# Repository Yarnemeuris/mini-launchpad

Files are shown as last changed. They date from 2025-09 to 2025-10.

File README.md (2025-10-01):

# mini-launchpad

Mini launchpad is a midi devicde and control surface for Ableton. When connected to a computer it can: send midi notes, start and stop clips, be used as audio output, change the volume and change paramaters. When not connected to a computer it can: play notes and create sound with a synth.

## connected to Ableton

Mini launchpad is specificy designed to be used with Ableton Live. When you connect it to a computer, it uses an internal usb hub so you can use it as an audio output and send commands through Ableton. When connected it can be used as a midi keyboard or start and stop cilps in the session view.

## standalone

When mini launchpad is in standalone mode, you can only use the midi keyboard. This will send midi into a synthesizer, which will then play sound. The syth can be customized a bit via the encoders at the top, but you can customize it fully if you reprogram the pi.

## compontents

Mini Launchpad has an 8x8 grid of buttons, wired to 4 io expanders. There are also 8 encoders connected to another io expander. The io expanders are used so that the microcontroller doesn't have to poll for changes, but that it can use interupts instead. This way every button press will be registerd and you can press every button at the same time. There are also some extra controll buttons and lights that are wired directly to the microcontroller. But these will also use interupt.

For audio there is a PCM5100 I²S DAC. This will convert the digital audio to a line output. Then there is an amplifier that amplifies the sound. You can also just use the line out.

## playing notes

Actually playing notes is a big part of the luanchpad. There are 2 ways to do this.
- Option 1 is that the notes are layed out linearly. This means that in the bottom left corner is a C, moving right goes up a note and moving up goes up an octave. You can change the octave of the rows by moving up and down. This is also the default option when the launchpad boots up. It looks like this:

layout 1

- Option 2 is for the notes to be layed out in a c scale. The bottom left note is still a C and going right still goes up a note. But going up goes up a fourth instead of an octave. This layout is the default layout on the Ableton Push and lloks like this:

layout 2

## progress

The current progress.

- [x] Design the schematic.
- [x] Design the pcb.
- [x] Design the case.
- [x] Write the firmware.

I know not a lot of the features I talk about aren't implemented yet. But for SoM those won't be included. This is beacuse mini midi magic started pretty late and it doesn't really have an end date yet. So by the end of mini midi magic this will all be implemented. The current features that aren't implemented are:
- Connecting to Ableton Live.
- Playing and controlling things in Ableton Live.
- Having a more complex and better synthesizer.
- Being able to change the synthesizer.
- Using the launchpad as an audio interface.
- And I might even add more features.

  I am also unsure if any of the code works and if the case is fully correct. Because I don't have the physical board myself. This will also change before the end of mini midi magic.

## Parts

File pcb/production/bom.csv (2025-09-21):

Designator | Footprint | Quantity | Value | LCSC Part #
C1, C17, C18, C2, C21, C22 | 0805 | 6 | 10µF | C15850
C10, C11, C12, C13, C14, C4, C5, C7, C8, C9 | 0805 | 10 | 100nF | C476766
C15, C16 | 0805 | 2 | 22pF | C1804
C19 | 1206 | 1 | 250µF
C20, C23 | 0805 | 2 | 50nF | C107154
C24 | 1206 | 1 | 250µF | C412252
C3, C6 | 0805 | 2 | 1µF | C28323
D1, D2, D3 | LED_D3.0mm | 3 | LED | C3028820
J1 | PinHeader_1x08_P2.54mm_Vertical | 1 | Conn_01x08_Socket
J2 | PinHeader_1x06_P2.54mm_Vertical | 1 | Conn_01x06_Socket | C5383115
J4 | Jack_3.5mm_CUI_SJ1-3524N_Horizontal | 1 | AudioJack3_Ground | C4992816
J5 | USB_C_Receptacle_G-Switch_GT-USB-7010ASV | 1 | USB_C_Receptacle_USB2.0_16P | C2988369
Q1 | SOT-23 | 1 | AO3401A | C15127
R1, R16 | 0402 | 2 | 5.1K | C105872
R10, R13 | 0402 | 2 | 10 | C138066
R11, R12, R4 | 0402 | 3 | 10K
R14, R15 | 0402 | 2 | 100 | C106232
R2, R3 | 0402 | 2 | 27 | C138021
R5, R7 | 0402 | 2 | 1K | C11702
R6, R8, R9 | 0402 | 3 | 220 | C112291
RV2 | Potentiometer_Alpha_RD902F-40-00D_Dual_Vertical | 1 | R_Potentiometer_Dual | C470285
SW1, SW10, SW11, SW12, SW13, SW14, SW15, SW16, SW17, SW18, SW19, SW2, SW20, SW21, SW22, SW23, SW24, SW25, SW26, SW27, SW28, SW29, SW3, SW30, SW31, SW32, SW33, SW34, SW35, SW36, SW37, SW38, SW39, SW4, SW40, SW41, SW42, SW43, SW44, SW45, SW46, SW47, SW48, SW49, SW5, SW50, SW51, SW52, SW53, SW54, SW55, SW56, SW57, SW58, SW59, SW6, SW60, SW61, SW62, SW63, SW64, SW7, SW8, SW9 | SW_Cherry_MX_1.00u_PCB | 64 | ~
SW65 | SW_E-Switch_EG2219_DPDT_Angled | 1 | SW_DPDT_x2 | C2848873
SW66, SW67, SW68, SW69, SW70, SW71, SW72, SW73 | RotaryEncoder_Alps_EC11E-Switch_Vertical_H20mm_MountingHoles | 8 | RotaryEncoder_Switch_MP | C202365
SW75, SW76, SW77, SW78, SW79, SW80, SW81, SW83 | SW_Cherry_MX_1.00u_PCB | 8 | SW_Push
U1, U11, U2, U3, U4 | QFN-28-1EP_6x6mm_P0.65mm_EP4.25x4.25mm | 5 | MCP23017_ML | C639770
U10 | SOIC-8_5.3x5.3mm_P1.27mm | 1 | W25Q128JVS | C97521
U14, U15 | SOIC-8_3.9x4.9mm_P1.27mm | 2 | LM386 | C23573
U5 | QFN-32-1EP_5x5mm_P0.5mm_EP3.3x3.3mm | 1 | CP2615-xx-xM | C1521596
U6 | TSSOP-16_4.4x5mm_P0.65mm | 1 | TMUX1574PW | C2673443
U7 | QSOP-16_3.9x4.9mm_P0.635mm | 1 | CH334R | C4154405
U8 | QFN-56-1EP_7x7mm_P0.4mm_EP3.2x3.2mm | 1 | RP2040 | C2040
U9 | TO-252-2 | 1 | NCP1117-3.3_TO252 | C154606
Y1 | Crystal_SMD_3225-4Pin_3.2x2.5mm | 1 | 12MHz | C9002

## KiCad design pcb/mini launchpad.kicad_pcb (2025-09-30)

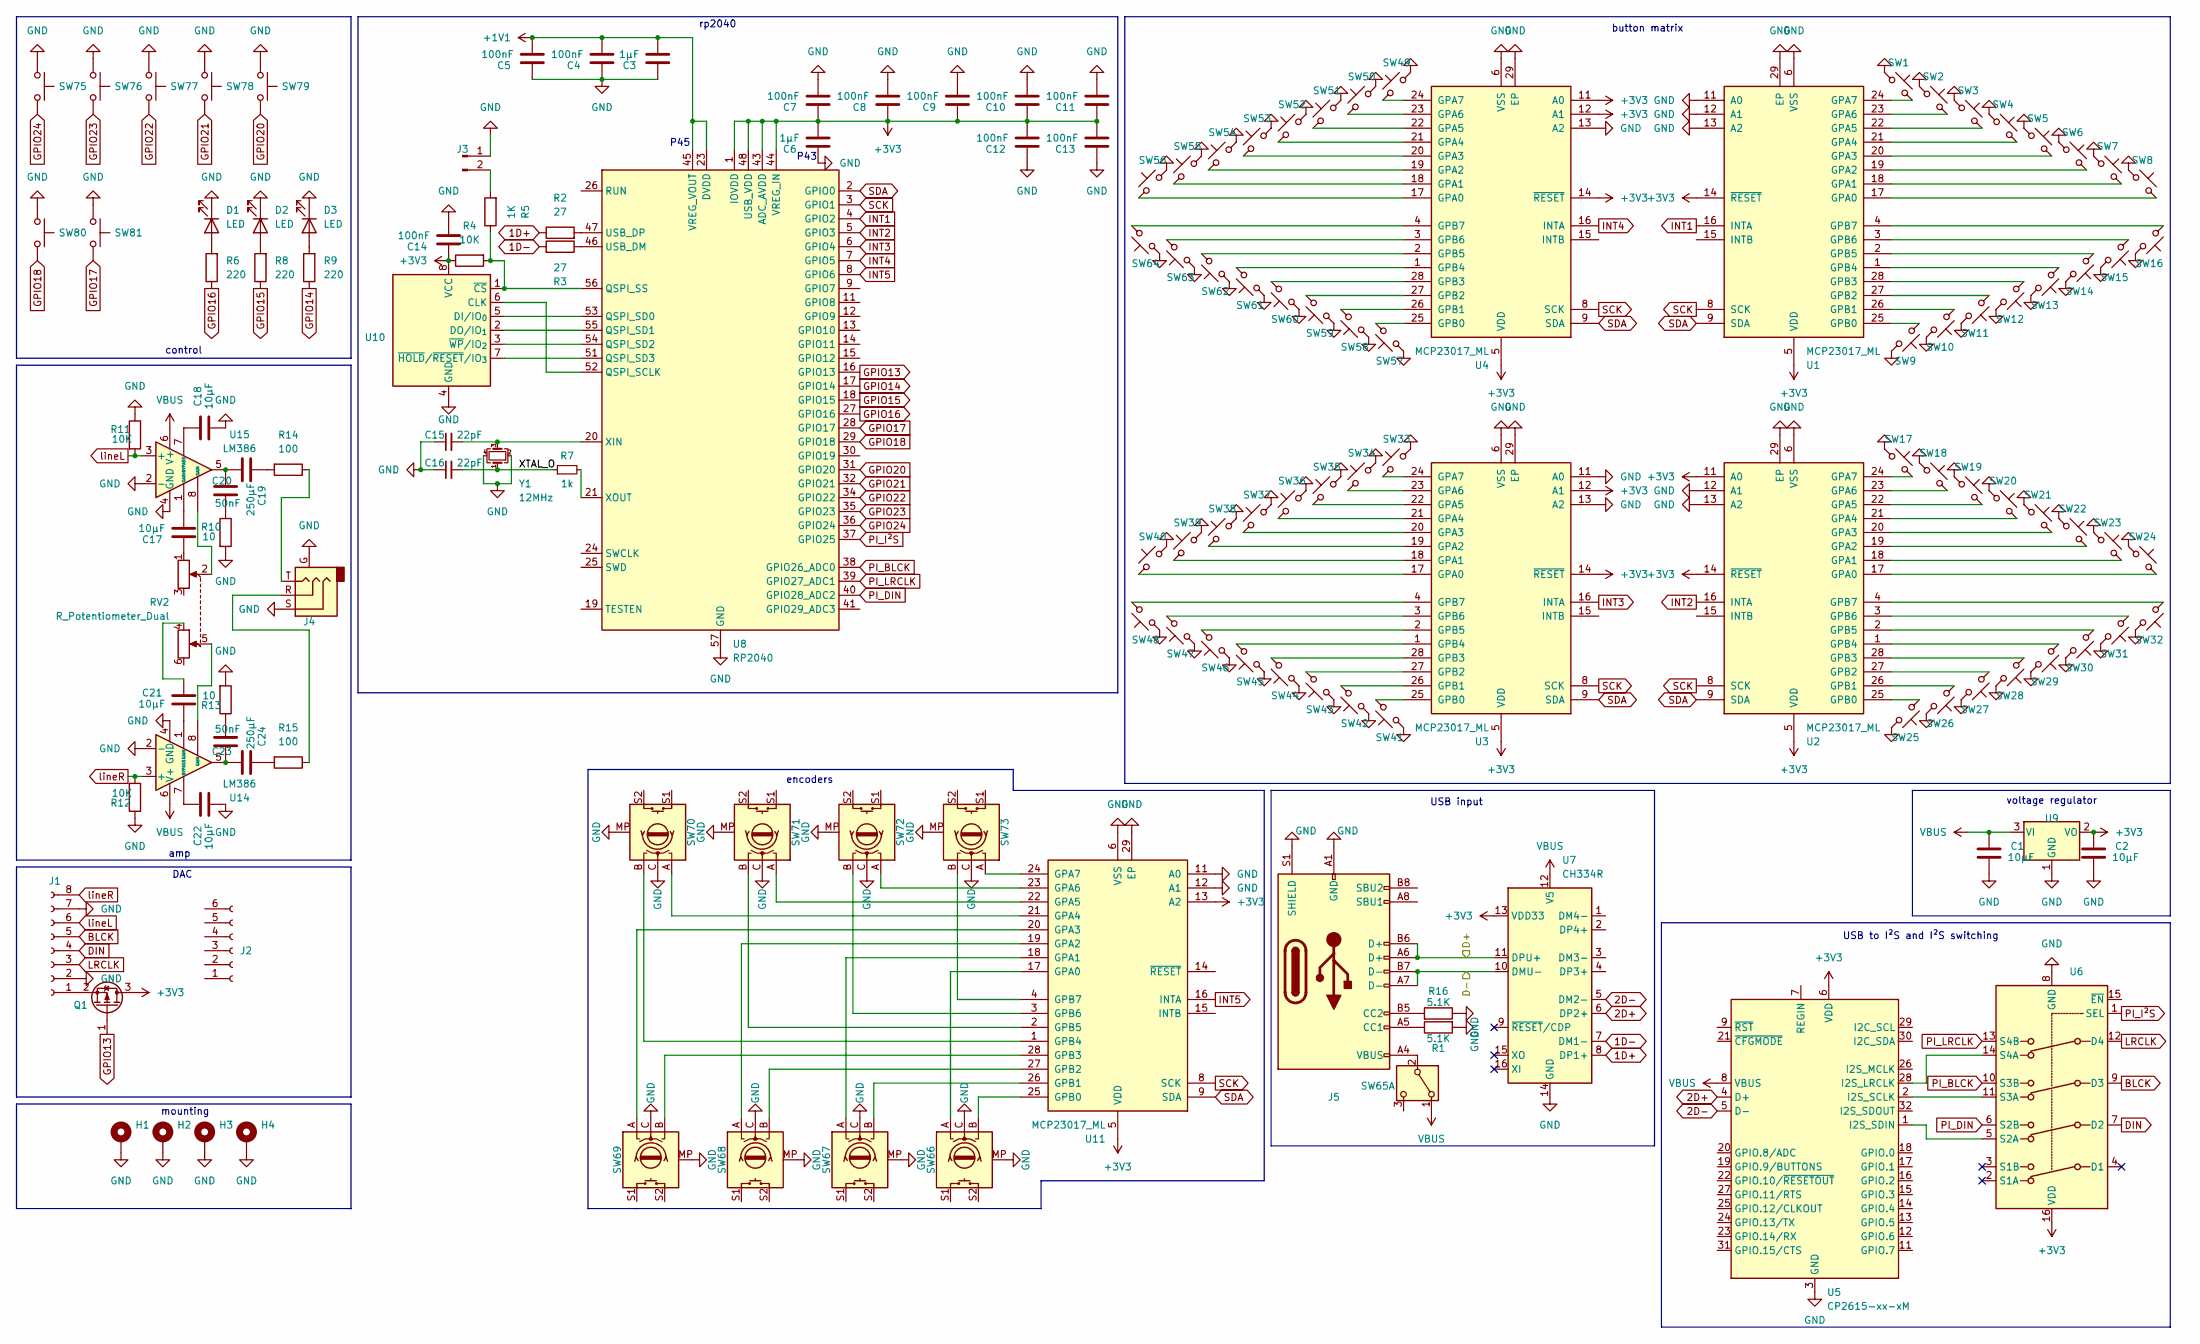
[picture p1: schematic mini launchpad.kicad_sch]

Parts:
C1, C2, C17, C18, C21, C22: 10µF; C_0805_2012Metric; LCSC Part C15850
C3, C6: 1µF; C_0805_2012Metric; LCSC Part C28323
C4, C5, C7, C8, C9, C10, C11, C12, C13, C14: 100nF; C_0805_2012Metric; LCSC Part C476766
C15, C16: 22pF; C_0805_2012Metric; LCSC C1804
C19, C24: 250µF; C_1206_3216Metric; LCSC Part C412252
C20, C23: 50nF; C_0805_2012Metric; LCSC Part C107154
D1, D2, D3: LED; LED_D3.0mm; LCSC Part C3028820
H1, H2, H3, H4: MountingHole_Pad; MountingHole_3.2mm_M3_Pad_TopOnly
J1: Conn_01x08_Socket; PinHeader_1x08_P2.54mm_Vertical; LCSC part C492407
J2: Conn_01x06_Socket; PinHeader_1x06_P2.54mm_Vertical; LCSC Part C5383115
J3: Conn_01x02_Pin; PinHeader_1x02_P2.54mm_Horizontal; LCSC Part C42431827
J4: AudioJack3_Ground; Jack_3.5mm_CUI_SJ1-3524N_Horizontal; LCSC Part C4992816
J5: USB_C_Receptacle_USB2.0_16P; USB_C_Receptacle_G-Switch_GT-USB-7010ASV; LCSC Part C2988369
Q1: AO3401A; SOT-23; LCSC Part C15127
R1, R16: 5.1K; R_0402_1005Metric; LCSC Part C105872
R2, R3: 27; R_0402_1005Metric; LCSC Part C138021
R4, R11, R12: 10K; R_0402_1005Metric
R5: 1K; R_0402_1005Metric; LCSC Part C11702
R6, R8, R9: 220; R_0402_1005Metric; LCSC Part C112291
R7: 1k; R_0402_1005Metric; LCSC C11702
R10, R13: 10; R_0402_1005Metric; LCSC Part C138066
R14, R15: 100; R_0402_1005Metric; LCSC Part C106232
RV2: R_Potentiometer_Dual; Potentiometer_Alpha_RD902F-40-00D_Dual_Vertical; LCSC Part C470285
SW1, SW2, SW3, SW4, SW5, SW6, SW7, SW8, SW9, SW10, SW11, SW12, SW13, SW14, SW15, SW16, SW17, SW18, SW19, SW20, SW21, SW22, SW23, SW24, SW25, SW26, SW27, SW28, SW29, SW30, SW31, SW32, SW33, SW34, SW35, SW36, SW37, SW38, SW39, SW40, SW41, SW42, SW43, SW44, SW45, SW46, SW47, SW48, SW49, SW50, SW51, SW52, SW53, SW54, SW55, SW56, SW57, SW58, SW59, SW60, SW61, SW62, SW63, SW64: SW_Cherry_MX_1.00u_PCB
SW65: SW_DPDT_x2; SW_E-Switch_EG2219_DPDT_Angled; LCSC Part C2848873
SW66, SW67, SW68, SW69, SW70, SW71, SW72, SW73: RotaryEncoder_Switch_MP; RotaryEncoder_Alps_EC11E-Switch_Vertical_H20mm_MountingHoles; LCSC Part C202365
SW75, SW76, SW77, SW78, SW79, SW80, SW81: SW_Push; SW_Cherry_MX_1.00u_PCB
U1, U2, U3, U4, U11: MCP23017_ML; QFN-28-1EP_6x6mm_P0.65mm_EP4.25x4.25mm; LCSC Part C639770
U5: CP2615-xx-xM; QFN-32-1EP_5x5mm_P0.5mm_EP3.3x3.3mm; LCSC Part C1521596
U6: TMUX1574PW; TSSOP-16_4.4x5mm_P0.65mm; LCSC Part C2673443
U7: CH334R; QSOP-16_3.9x4.9mm_P0.635mm; LCSC Part C4154405
U8: RP2040; QFN-56-1EP_7x7mm_P0.4mm_EP3.2x3.2mm; LCSC Part C2040
U9: NCP1117-3.3_TO252; TO-252-2; LCSC Part C154606
U10: W25Q128JVS; SOIC-8_5.3x5.3mm_P1.27mm; LCSC Part C97521
U14, U15: LM386; SOIC-8_3.9x4.9mm_P1.27mm; LCSC Part C23573
Y1: 12MHz; Crystal_SMD_3225-4Pin_3.2x2.5mm; LCSC Part C9002

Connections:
1D+: R2.1, U7.8 (DP1+)
1D-: R3.2, U7.7 (DM1-)
2D+: U5.4 (D+), U7.6 (DP2+)
2D-: U5.5 (D-), U7.5 (DM2-)
+1V1: C3.1, C4.1, C5.1, U8.23 (DVDD), U8.45 (VREG_VOUT), U8.50 (DVDD)
+3V3: C2.2, C6.1, C7.2, C8.2, C9.2, C10.2, C11.2, C12.1, C13.1, C14.2, Q1.3 (D), R4.1, U1.5 (VDD), U1.14 (~RESET), U2.5 (VDD), U2.11 (A0), U2.14 (~RESET), U3.5 (VDD), U3.12 (A1), U3.14 (~RESET), U4.5 (VDD), U4.11 (A0), U4.12 (A1), U4.14 (~RESET), U5.6 (VDD), U6.16 (VDD), U7.13 (VDD33), U8.1 (IOVDD), U8.10 (IOVDD), U8.22 (IOVDD), U8.33 (IOVDD), U8.42 (IOVDD), U8.43 (ADC_AVDD), U8.44 (VREG_IN), U8.48 (USB_VDD), U8.49 (IOVDD), U9.2 (VO), U10.8 (VCC), U11.5 (VDD), U11.13 (A2)
/D+: J5.A6 (D+), J5.B6 (D+), U7.11 (DPU+)
/D-: J5.A7 (D-), J5.B7 (D-), U7.10 (DMU-)
/XTAL_O: C16.2, R7.1, Y1.1
BLCK: J1.5, U6.9 (D3)
DIN: J1.4, U6.7 (D2)
GND: C1.1, C2.1, C3.2, C4.2, C5.2, C6.2, C7.1, C8.1, C9.1, C10.1, C11.1, C12.2, C13.2, C14.1, C15.1, C16.1, C18.1, C22.1, D1.1 (K), D2.1 (K), D3.1 (K), H1.1, H2.1, H3.1, H4.1, J1.2, J1.7, J3.1, J4.G, J4.S, J5.A1 (GND), J5.A12 (GND), J5.B1 (GND), J5.B12 (GND), J5.S1 (SHIELD), R1.2, R10.2, R11.1, R12.1, R13.2, R16.1, SW1.1, SW2.1, SW3.1, SW4.1, SW5.1, SW6.1, SW7.1, SW8.1, SW9.1, SW10.1, SW11.1, SW12.1, SW13.1, SW14.1, SW15.1, SW16.1, SW17.1, SW18.1, SW19.1, SW20.1, SW21.1, SW22.1, SW23.1, SW24.1, SW25.1, SW26.1, SW27.1, SW28.1, SW29.1, SW30.1, SW31.1, SW32.1, SW33.1, SW34.1, SW35.1, SW36.1, SW37.1, SW38.1, SW39.1, SW40.1, SW41.1, SW42.1, SW43.1, SW44.1, SW45.1, SW46.1, SW47.1, SW48.1, SW49.1, SW50.1, SW51.1, SW52.1, SW53.1, SW54.1, SW55.1, SW56.1, SW57.1, SW58.1, SW59.1, SW60.1, SW61.1, SW62.1, SW63.1, SW64.1, SW66.C, SW66.MP, SW67.C, SW67.MP, SW68.C, SW68.MP, SW69.C, SW69.MP, SW70.C, SW70.MP, SW71.C, SW71.MP, SW72.C, SW72.MP, SW73.C, SW73.MP, SW75.1, SW76.1, SW77.1, SW78.1, SW79.1, SW80.1, SW81.1, U1.6 (VSS), U1.11 (A0), U1.12 (A1), U1.13 (A2), U1.29 (EP), U2.6 (VSS), U2.12 (A1), U2.13 (A2), U2.29 (EP), U3.6 (VSS), U3.11 (A0), U3.13 (A2), U3.29 (EP), U4.6 (VSS), U4.13 (A2), U4.29 (EP), U5.3 (GND), U5.33 (GND), U6.8 (GND), U7.14 (GND), U8.57 (GND), U9.1 (GND), U10.4 (GND), U11.6 (VSS), U11.11 (A0), U11.12 (A1), U11.29 (EP), U14.2 (-), U14.4 (GND), U15.2 (-), U15.4 (GND), Y1.2, Y1.4
GPIO13: Q1.1 (G), U8.16 (GPIO13)
GPIO14: R9.1, U8.17 (GPIO14)
GPIO15: R8.1, U8.18 (GPIO15)
GPIO16: R6.1, U8.27 (GPIO16)
GPIO17: SW81.2, U8.28 (GPIO17)
GPIO18: SW80.2, U8.29 (GPIO18)
GPIO20: SW79.2, U8.31 (GPIO20)
GPIO21: SW78.2, U8.32 (GPIO21)
GPIO22: SW77.2, U8.34 (GPIO22)
GPIO23: SW76.2, U8.35 (GPIO23)
GPIO24: SW75.2, U8.36 (GPIO24)
INT1: U1.16 (INTA), U8.4 (GPIO2)
INT2: U2.16 (INTA), U8.5 (GPIO3)
INT3: U3.16 (INTA), U8.6 (GPIO4)
INT4: U4.16 (INTA), U8.7 (GPIO5)
INT5: U8.8 (GPIO6), U11.16 (INTA)
LRCLK: J1.3, U6.12 (D4)
unnamed: C17.1, U15.1 (GAIN)
unnamed: C17.2, RV2.1
unnamed: C19.1, C20.1, U15.5
unnamed: C19.2, R14.2
unnamed: C20.2, R10.1
unnamed: C21.1, U14.1 (GAIN)
unnamed: C21.2, RV2.4
unnamed: C23.1, C24.1, U14.5
unnamed: C23.2, R13.1
unnamed: C24.2, R15.2
unnamed: D1.2 (A), R6.2
unnamed: D2.2 (A), R8.2
unnamed: D3.2 (A), R9.2
unnamed: J1.1, Q1.2 (S)
unnamed: J3.2, R5.2
unnamed: J4.R, R15.1
unnamed: J4.T, R14.1
unnamed: J5.A5 (CC1), R1.1
unnamed: J5.B5 (CC2), R16.2
unnamed: RV2.2, U15.8 (GAIN)
unnamed: RV2.5, U14.8 (GAIN)
unnamed: J5.A4 (VBUS), J5.A9 (VBUS), J5.B4 (VBUS), J5.B9 (VBUS), SW65.2 (B)
unnamed: SW8.2, U1.17 (GPA0)
unnamed: SW7.2, U1.18 (GPA1)
unnamed: SW6.2, U1.19 (GPA2)
unnamed: SW5.2, U1.20 (GPA3)
unnamed: SW4.2, U1.21 (GPA4)
unnamed: SW3.2, U1.22 (GPA5)
unnamed: SW2.2, U1.23 (GPA6)
unnamed: SW1.2, U1.24 (GPA7)
unnamed: SW9.2, U1.25 (GPB0)
unnamed: SW10.2, U1.26 (GPB1)
unnamed: SW11.2, U1.27 (GPB2)
unnamed: SW12.2, U1.28 (GPB3)
unnamed: SW13.2, U1.1 (GPB4)
unnamed: SW14.2, U1.2 (GPB5)
unnamed: SW15.2, U1.3 (GPB6)
unnamed: SW16.2, U1.4 (GPB7)
unnamed: SW24.2, U2.17 (GPA0)
unnamed: SW23.2, U2.18 (GPA1)
unnamed: SW22.2, U2.19 (GPA2)
unnamed: SW21.2, U2.20 (GPA3)
unnamed: SW20.2, U2.21 (GPA4)
unnamed: SW19.2, U2.22 (GPA5)
unnamed: SW18.2, U2.23 (GPA6)
unnamed: SW17.2, U2.24 (GPA7)
unnamed: SW25.2, U2.25 (GPB0)
unnamed: SW26.2, U2.26 (GPB1)
unnamed: SW27.2, U2.27 (GPB2)
unnamed: SW28.2, U2.28 (GPB3)
unnamed: SW29.2, U2.1 (GPB4)
unnamed: SW30.2, U2.2 (GPB5)
unnamed: SW31.2, U2.3 (GPB6)
unnamed: SW32.2, U2.4 (GPB7)
unnamed: SW40.2, U3.17 (GPA0)
unnamed: SW39.2, U3.18 (GPA1)
unnamed: SW38.2, U3.19 (GPA2)
unnamed: SW37.2, U3.20 (GPA3)
unnamed: SW36.2, U3.21 (GPA4)
unnamed: SW35.2, U3.22 (GPA5)
unnamed: SW34.2, U3.23 (GPA6)
unnamed: SW33.2, U3.24 (GPA7)
unnamed: SW41.2, U3.25 (GPB0)
unnamed: SW42.2, U3.26 (GPB1)
unnamed: SW43.2, U3.27 (GPB2)
unnamed: SW44.2, U3.28 (GPB3)
unnamed: SW45.2, U3.1 (GPB4)
unnamed: SW46.2, U3.2 (GPB5)
unnamed: SW47.2, U3.3 (GPB6)
unnamed: SW48.2, U3.4 (GPB7)
unnamed: SW56.2, U4.17 (GPA0)
unnamed: SW55.2, U4.18 (GPA1)
unnamed: SW54.2, U4.19 (GPA2)
unnamed: SW53.2, U4.20 (GPA3)
unnamed: SW52.2, U4.21 (GPA4)
unnamed: SW51.2, U4.22 (GPA5)
unnamed: SW50.2, U4.23 (GPA6)
unnamed: SW49.2, U4.24 (GPA7)
unnamed: SW57.2, U4.25 (GPB0)
unnamed: SW58.2, U4.26 (GPB1)
unnamed: SW59.2, U4.27 (GPB2)
unnamed: SW60.2, U4.28 (GPB3)
unnamed: SW61.2, U4.1 (GPB4)
unnamed: SW62.2, U4.2 (GPB5)
unnamed: SW63.2, U4.3 (GPB6)
unnamed: SW64.2, U4.4 (GPB7)
unnamed: U5.28 (I2S_LRCLK), U6.14 (S4A)
unnamed: U5.2 (I2S_SCLK), U6.11 (S3A)
unnamed: U5.1 (I2S_SDIN), U6.5 (S2A)
unnamed: R3.1, U8.46 (USB_DM)
unnamed: R2.2, U8.47 (USB_DP)
unnamed: C15.2, U8.20 (XIN), Y1.3
unnamed: R7.2, U8.21 (XOUT)
unnamed: U8.52 (QSPI_SCLK), U10.6 (CLK)
unnamed: U8.53 (QSPI_SD0), U10.5 (DI/IO_{0})
unnamed: U8.55 (QSPI_SD1), U10.2 (DO/IO_{1})
unnamed: R4.2, R5.1, U8.56 (QSPI_SS), U10.1 (~CS)
unnamed: U8.51 (QSPI_SD3), U10.7 (~HOLD/~RESET/IO_{3})
unnamed: U8.54 (QSPI_SD2), U10.3 (~WP/IO_{2})
unnamed: SW66.A, U11.17 (GPA0)
unnamed: SW67.A, U11.18 (GPA1)
unnamed: SW68.A, U11.19 (GPA2)
unnamed: SW69.A, U11.20 (GPA3)
unnamed: SW70.A, U11.21 (GPA4)
unnamed: SW71.A, U11.22 (GPA5)
unnamed: SW72.A, U11.23 (GPA6)
unnamed: SW73.A, U11.24 (GPA7)
unnamed: SW66.B, U11.25 (GPB0)
unnamed: SW67.B, U11.26 (GPB1)
unnamed: SW68.B, U11.27 (GPB2)
unnamed: SW69.B, U11.28 (GPB3)
unnamed: SW70.B, U11.1 (GPB4)
unnamed: SW71.B, U11.2 (GPB5)
unnamed: SW72.B, U11.3 (GPB6)
unnamed: SW73.B, U11.4 (GPB7)
unnamed: C22.2, U14.7 (BYPASS)
unnamed: C18.2, U15.7 (BYPASS)
PI_BLCK: U6.10 (S3B), U8.38 (GPIO26_ADC0)
PI_DIN: U6.6 (S2B), U8.40 (GPIO28_ADC2)
PI_I²S: U6.1 (SEL), U8.37 (GPIO25)
PI_LRCLK: U6.13 (S4B), U8.39 (GPIO27_ADC1)
SCK: U1.8 (SCK), U2.8 (SCK), U3.8 (SCK), U4.8 (SCK), U8.3 (GPIO1), U11.8 (SCK)
SDA: U1.9 (SDA), U2.9 (SDA), U3.9 (SDA), U4.9 (SDA), U8.2 (GPIO0), U11.9 (SDA)
VBUS: C1.2, SW65.1 (A), U5.8 (VBUS), U7.12 (V5), U9.3 (VI), U14.6 (V+), U15.6 (V+)
lineL: J1.6, R11.2, U15.3 (+)
lineR: J1.8, R12.2, U14.3 (+)

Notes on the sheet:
rp2040
button matrix
USB to I²S and I²S switching
P43
control
amp
mounting
DAC
encoders
USB input
voltage regulator
P45

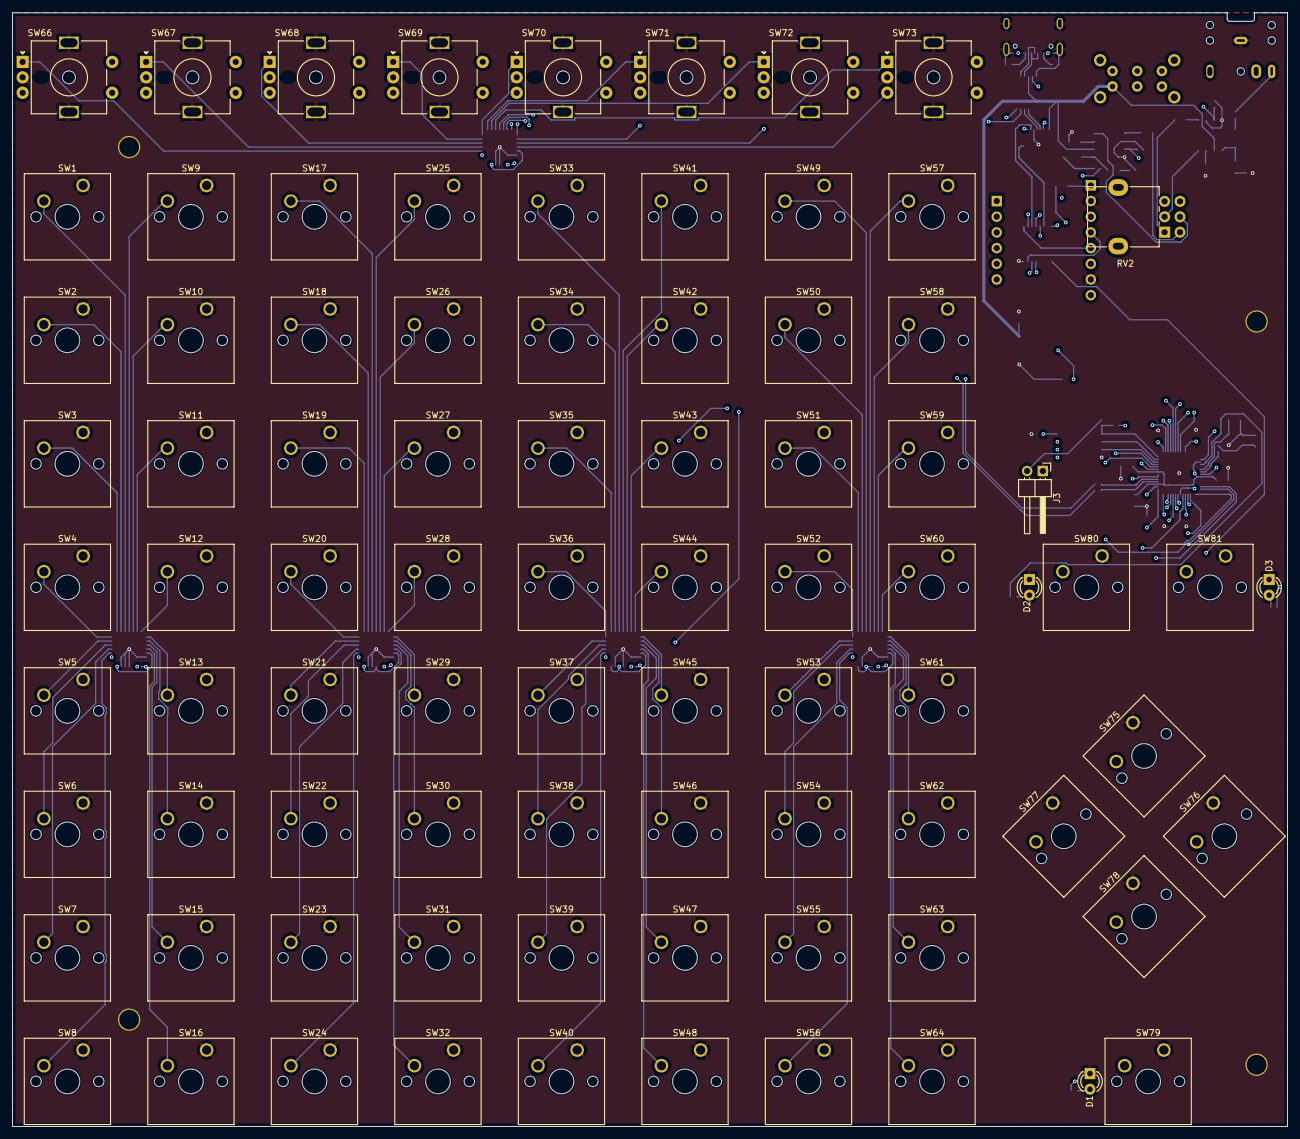
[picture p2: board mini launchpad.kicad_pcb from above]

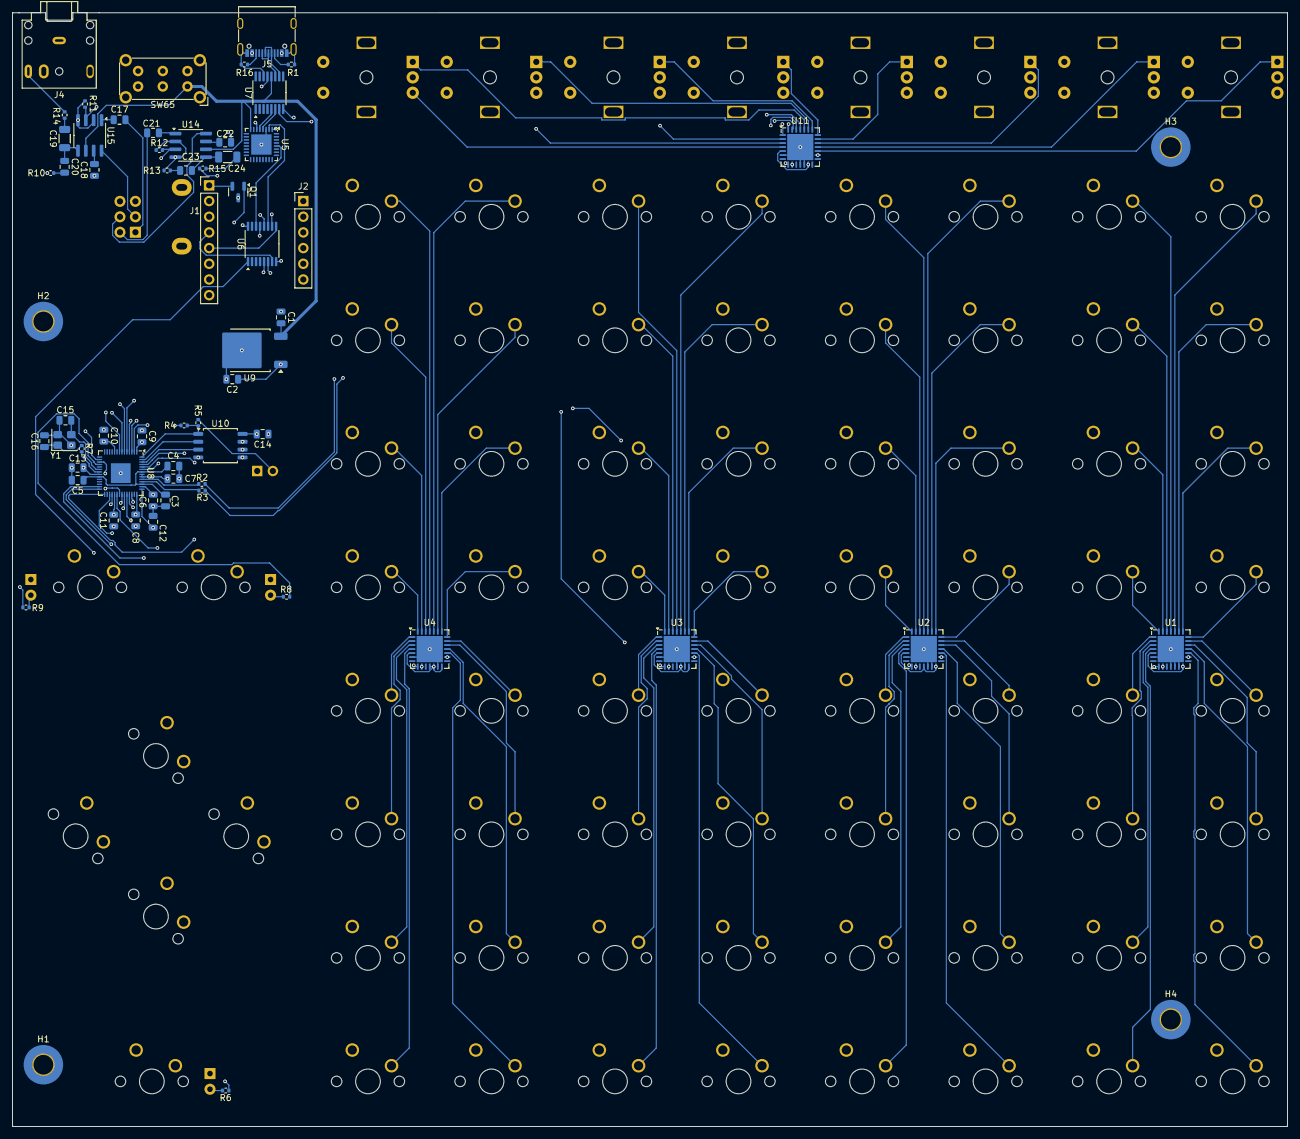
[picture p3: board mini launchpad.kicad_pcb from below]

Board: 4 copper layers, 206.5 x 180.3 mm, 148 parts (64 on the bottom side), 155 nets.

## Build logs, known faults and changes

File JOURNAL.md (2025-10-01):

# September 3th: Started working on the schematic.

Firstly I looked at the tutorial and made the button grid. I chose to use 4 16 pin IO expanders for this. Because I can see every button's state, and I can use interupt instead of polling. I chose to make the grid 8x8, because at that size you can do a lot with it, and it isn't too big. then I tried looking to how I wanted to make the control surface. I want to make it have an audio interface, so that you can output your pc sound via the DAC. But I can't find a usb to I²S chip in kiCad. My plan currently is to have a internal usb hub. That will have the pi and the usb interface connected to it. When you plug it in to a computer, the pi will send midi to Ableton, and to audio will go via the usb interface. But when you are not connected to a computer. It will play the midi notes via the line out itself. So you don't need a computer to use it. But I don't know if I will find a usb to I²S chip.

**Total time spent: 7h**

# September 6th: Continued working on the schematic.

I finally made a github repo. I didn't do it before because I wsan't sure of the name. But now that i have the repo I can use photo's. So this is what I ended up with today:

schematic

I changed from a pico to the rp2040 itself. The only reason I did this was so that I could route the usb on the pcb and didn't have to use a cable. The only thing with not using the pico is that, I have to route the sensitve wires on the pcb. To connect the 2040 I followed the [hardware design with RP2040](https://datasheets.raspberrypi.com/rp2040/hardware-design-with-rp2040.pdf) datasheet from raspberry pi themself. But ot does say that a lot of component have to be close to the chip, like the decoupling caps. So it will be fun when I design the pcb. following the datasheet went pretty well. Until the crystal oscillator. I couldn't find the execpt part in KiCad and from reading the datasheet, it looks like I can't just choos some other random one I can find. So I used thzt part from [Calliahs designguide](https://github.com/calliah333/RP2040-designguide/tree/main). I also found a usb to I²S chip in KiCad:

I²S switching

So I connected it and added a quadrupel mux, to switch between the 2040 and usb. There are still some pins on the rp2040 which I probably should connect to something. But I'll do that next time.

**Total time spent: 3h**

# September 7th: Added encoders.

I added 8 encoders to another io expander.

encoders

The reason I use io expanders is just for the easy interupts. That way I have easier code anddon't have to poll the encoders at a fast rate to get every change. I'm also going to dupple dip with SoM so I downloaded the KiCad-wakatime plugin. Hopefully it will work well for me. That was it for today, I didn't do much.

**Total time spent: 0.5h**

# September 8th: Started adding the control buttons.

So I started adding some buttons for control. Like playing, pausing, changing mode, etc.

control buttons

But it has me questioning everything. What do I want it to do. Do I add those features, but then I should also add that.

I didn't make much progress today. But now I have more thing I can think about and decide during boring school lessons.

**Total time spent: 0.5h**

# September 11th: Added an amplifier.

So I finished the control buttons. I think I know what features I want.

control buttons

There will be 4 buttons for moving, 1 for play/pause. 2 for switching between midi keyboard and clip start/stop with a led under each to show which is selected, this will also controll the what the encoders do. These 2 buttons are only for if you are connected to Ableton. The last button is for switching between midi device without a computer and being a controller for ableton, which will also have a led. I noticed while explaining all the buttons that I had one to many. Maybe I counted wrong or I kind of forgot what it was for.

I also added an amplifier:

amp

So that the line level output can be used to drive speakers or headphones. This was kind of complicated so I did a lot of research te previous days. That way there isn't a journal log, I just spent some time looking thinges up. first I thought I needed to create my own amp using a tranistor. But I found out that I can just use a chip for that. But because this seems likly to not work at all or perfectly, I will also add a pin header for the line output. The only things I think I still need is That and the connector for the DAC. Than the schematic should be done. I'm gonna ask if it is possible to review it, beacuse it's pretty complicated and I'm not sure I wired everything correctly.

**Total time spent: 3h**

# September 13th: Started on the pcb.

I finally finished the schematic. So I started working on laying everything out on the pcb. I'm gonna make it a 4 layer pcb. I started with adding the buttons:

buttons

I wanted to space them out 20 mm. But I messed somthing up and now they're 22.857. I will probiably change this tomorrow. Aside from the buttons and encoders I didn't do much on the pcb. I started with the usb and power ut that still needs a lot of components. I should also make some of the capasitors larger. Because this does not look good for the power circuit:

small cap

The last thing that I did today was update the README. So now there's finally something there.

**Total time spent: 2h**

# September 14th: The pcb is almost finished.

pcb

First I changed the buttons to be 20mm apart. It wasn't as bad as I though it would be. Then I connected the amp, the connector, usb hub. It just went pretty fast. So that now of the 952 pads, 242 nets there are only 20 unrouted connections. The only problem is the rp2040 chip.

rp2040 connections

It has so many connections and they are so close to together and everything has to be close to it. But there are only some gpio connections left, so it should not be too hard.

**Total time spent: 2h**

# September 15th: Finished the pcb.

This is the entire pcb:

full pcb

I connected the last pins, which were the hardest to connect. They were almost all on the rp2040 chip. I also switched the usb C connector, because I didn't like it's footprint. Probiably don't have to do much more on the pcb, just change a few components if jlc doesn't have these.

**Total time spent: 1h**

# September 16th: Added lcsc part numbers.

 I started adding lcsc part numbers to every component. Just to make sure jlcpcb uses the same part. But because this is all inside the fields, I can't really show a picture.

 **Total time spent: 0.5h**

# September 17th: Finished the pcb.

I finally finished the pcb.

pcb

I added all the LCSC Part numbers. I check if everything worked on jlcpcb, there are some issues but you can set every part in jlcpcb. I did see that the price for the board is like $200 so I might change some things. The things you have to change when ordering are: some components aren't found in jlcpcb library or some other problems with the bom and because jlcpcb does the rotation diffrently you have to rotate most components in the viewer.
Today I also started on the cad but it isn't much yet.

**Total time spent: 2h**

# September 18th: Started designing the cad.



This is what I designed so far. It's mostly just the buttons, encoders and a the audio port. It also includes some mounting internally with M3 bolts and inserts. I will probably change the pcb to make it smaller, because right now the case doesn't fit on my printers bed.

**Total time spent: 1h**

# September 20th: Changed the pcb again.

So with the case around the pcb it doesn't fit on my printers build plate. So of course the best thing to do is redisgn the hole pcb to be smaller. So every surface mount component is now placed on the back, still just one side to assamble but the opposite side. This way the pcb can be smaller but you just have to solder every thing on the other side manually. The final resualt:

smaller pcb

It is just 180mmx206mm. So with 6mm either side for the case, it still fits on my printer. The final connections I will do tomorrow.

**Total time spent: 1.5h**

# September 21th: Finished the pcb.

Today I think I finally finished the pcb. Theonly thing I think I might change is removing a button. It now looks like this:

pcb v1.2

I also worked a bit on the case. It now looks like this:

case

It is almost finished too. Just the volume, some ports and maybe some more dacals. Thise I will also print myself. I will just say to thhe slicer that it has multipul toolheads and the change gcoe is just a color change. So this is actually almost finished. I just hope that I will finish before the end of SoM. Because I don't know what will happend if it's not shipped by the end. JLCPCB says it will be $174 for the board. But I will still have to order some more copmonents that I have to solder on myself. It is all the top components so buttons, encoders, things like that. Tommorow I will probably finish the case and can start on the firmware.

**Total time spent: 3h**

# September 22th: Finished the pcb again.

Today I just removed the top and moved the potentiometer to the center. The pcb should actually be finished now.

hopfully final pcb change

**Total time spent: 0.5h**

# September 23th: I think I finished the cad.

A lot of the cad work was already done before this. The only things I did was add the power switch, usb-c port and knob at the top. The usb-c port and knob are geussed and I will probably move and change these when I have the actually pcb.

case

**Total time spent: 0.5h**

# September 24th: Oh no problems again.

So I did some minor adjustments to the cad and then wanted to start on the firmware. So I moved the pcb files to a diffrent folder. But then the c sdk setup. I tried using the vs code plugin, but thzt gave me errors and I can't place it in a subfolder. So I either get a new hackatime project, which I don't want. Or I can't use the plugin. It is so bad, I might use python. I am not even sure which I will use now. But I don't think micropython even worked. I won't include pictures today because I don't really have anything to show. But I will ask how to set something up and commit the pcb files moved into a diffrent folder.

**Total time spent: 1h**

# September 25th: Started working on the firmware.

I chose to use micropython because C just didn't work even though I wanted to use it more. Currently all I did was setup the io expanders via i²c and set some pins.

first code

But just setting up the io expanders I had to read a lot of the datasheet to try to understand it. I would have done more today but had to learn a lot of things on maps for school.

**Total time spent: 1h**

# September 30th: Made some basic code.

I kind of forgot to journal the previous days. So to todays time I will add 2 hours. That is how long hackatime says I spent working on it for those days. But the first code is complete. I speedran this to try and get a ship before the end of SoM. Just as I was wrighting the devlog there was an announcment to say that we have time until October 2th. So I will spent some more time making it better until then. Currently you can only send notes to a computer and have it play them. The next things I will add are diffrent layouts for the notes and producing audio via the dac. This is the code I have for now:

code

**Total time spent: 3h**

# Oktober 1st: The first basic features are done.

I made it so that you can actually hear the notes that you are playing with a basic synthesizer. I also added a second layout and update the readme a bit. Today I the las day of SoM. Which means I shipped my project today. I don't know if my ship will be certified because i don't really have a demo and only the basic features are implemented in the firmware. I just hop that they will understand that it wouldn't be possible for me to have a demo yet. Because mini midi magic doesn't even have an end date yet and there would be no way that I would already have the pcb.

code

**Total time spent: 3h**

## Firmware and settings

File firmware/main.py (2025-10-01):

import _thread
import audiobusio # type: ignore
import audiocore # type: ignore
import board # type: ignore
import audiomixer # type: ignore
import array
from machine import *
import math
import usb_midi # type: ignore
import adafruit_midi # type: ignore

from adafruit_midi.note_off import NoteOff # type: ignore
from adafruit_midi.note_on import NoteOn # type: ignore

globalUpdates = {"pins": [], "noteBottem": 0, "noteLayout": "linear"}
notes = ["C", "D", "E", "F", "G", "A", "B"]
noteLayouts = ["linear", "scale"]
voices = [-1 for _ in range(8)]

#pins
midi = adafruit_midi.MIDI(
    midi_in=usb_midi.ports[0], in_channel=0, midi_out=usb_midi.ports[1], out_channel=0
)
dac = audiobusio.I2SOut(bit_clock=board.GP0, word_select=board.GP1, data=board.GP2)
mixer = audiomixer.Mixer(voice_count=8, sample_rate=8000, channel_count=1, bits_per_sample=8, samples_signed=False)

i2c = I2C(0, scl=Pin(1), sda=Pin(0))
PiI2s = Pin(25, Pin.OUT, value=0)
dacPower = Pin(13, Pin.OUT, value=0) # 0 is on
intPins = [Pin(i, Pin.IN, Pin.PULL_UP) for i in [0,1,2,3,6]]

movePins = [Pin(i, Pin.IN, Pin.PULL_UP) for i in [24,23,21,22]]
notePin = Pin(18, Pin.IN, Pin.PULL_UP)
pinStates = [[0 for _ in range(8)] for _ in range(8)]

#i²c setup
for i in range(0x20, 0x24+1):
    i2c.writeto_mem(i, 0x0A, 0b01010010)
    i2c.writeto_mem(i, 0x00, 0b11111111)
    i2c.writeto_mem(i, 0x01, 0b00000000)
    i2c.writeto_mem(i, 0x02, 0b00000000)
    i2c.writeto_mem(i, 0x03, 0b11111111)
    i2c.writeto_mem(i, 0x04, 0b11111111)
    i2c.writeto_mem(i, 0x05, 0b11111111)
    i2c.writeto_mem(i, 0x06, 0b11111111)
    i2c.writeto_mem(i, 0x07, 0b11111111)
    i2c.writeto_mem(i, 0x08, 0b00000000)
    i2c.writeto_mem(i, 0x09, 0b00000000)
    i2c.writeto_mem(i, 0x0C, 0b11111111)
    i2c.writeto_mem(i, 0x0D, 0b11111111)

dac.play(mixer)

# handel interupts
def getSetBits(byte, addvalue=0): #returns list of the indecies of all the bits that are set.
    if byte == 0: return []

    value = math.floor(math.log2(byte))
    return getSetBits(byte-2**value) + [value+addvalue]

def reverseByte(byte):
    return int(format(byte, "08b")[::-1], 2)

def I2CInterupt(pin):
    pinIndex = intPins.index(pin)
    data = list(i2c.readfrom_mem(0x20 + pinIndex, 0x0E, 4))

    data[0] = reverseByte(data[0]) #need to reverse the A gpio pins because they are wired in reverse to B
    data[2] = reverseByte(data[2])

    globalUpdates["pins"] = getSetBits(data[0], pinIndex*16) + getSetBits(data[1], pinIndex*16+8)

    for i in range(8):
        pinStates[pinIndex*2][i] = (data[2] & (2**(i+1))) != 0
        pinStates[pinIndex*2+1][i] = (data[3] & (2**(i+1))) != 0

def moveInterupt(pin):
    pinIndex = movePins.index(pin)

    if pinIndex == 0 or pinIndex == 2:
        globalUpdates["noteBottem"] -= (pinIndex-1)*8

def noteInterupt(pin):
    globalUpdates["noteLayout"] = noteLayouts[(noteLayouts.index(globalUpdates["noteLayout"])+1)%len(noteLayouts)]

# core 1 function
def core1():
    for pin in intPins:
        pin.irq(I2CInterupt, pin.IRQ_RISING)
    for pin in movePins:
        pin.irq(moveInterupt, pin.IRQ_RISING)
    
    notePin.irq(noteInterupt, notePin.IRQ_FALLING)

core1Thread = _thread.start_new_thread(core1)

def indexToNote(i):
    if globalUpdates["noteLayout"] == "linear":
        return notes[(i//8)%7] + str(8 - i%8 + globalUpdates["noteBottem"])

    elif globalUpdates["noteLayout"] == "scale":
        return notes[(i//8 + 4*((i)%8))%7] + str(math.floor(1+ (8-i%8)/2.4 + (i//8)/7)) # this should be correct without any transformations

def noteToFreq(note):
    return (440 / 32) * (2 ** ((note - 69) / 12))

def freqToSample(freq):
    length = 8000 // freq
    sine_wave = array.array("h", [0] * length)
    for i in range(length):
        sine_wave[i] = int(math.sin(math.pi * 2 * i / length) * (2 ** 15))
    return sine_wave

while True:
    if globalUpdates["pins"].count != 0:
        for index in globalUpdates["pins"]:
            pin = pinStates[index//8][index%8]
            note = indexToNote(index)

            if pin == 0:
                midi.send(NoteOff(note, 0))

                voiceIndex = voices.index(note) if note in voices else -1
                if voiceIndex != -1:
                    mixer.stop_voice(voiceIndex)
                    voices[voiceIndex] = -1

            elif pin == 1:
                midi.send(NoteOn(note, 100))

                voiceIndex = voices.index(-1) if -1 in voices else -1
                if voiceIndex != -1:
                    sample = audiocore.RawSample(freqToSample(noteToFreq(note)))
                    mixer.play(sample, voice=voiceIndex, loop=True)
                    voices[voiceIndex] = note

        globalUpdates["pins"].pop(index)

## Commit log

2025-09-06 added pcb
    [mini launchpad.kicad_pcb, mini launchpad.kicad_sch]
2025-09-06 pcb update
    [mini launchpad.kicad_pcb, mini launchpad.kicad_sch]
2025-09-07 schematic update
    [mini launchpad.kicad_sch]
2025-09-22 this time I swear it's the final pcb update
    [mini launchpad.kicad_pcb, mini launchpad.kicad_sch]
2025-09-24 folder changes firmware not working for me currently
    [bom.csv, designators.csv, mini launchpad.kicad_pcb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]
2025-09-30 basic code
    [mini launchpad.kicad_pcb, mini launchpad.kicad_sch]
2025-10-01 Code to make sound from button presses.
